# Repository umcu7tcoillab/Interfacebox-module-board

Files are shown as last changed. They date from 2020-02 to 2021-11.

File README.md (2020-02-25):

# Interfacebox module board

## About us
This design has been made by the coil-lab of the High Field MRI Group of the UMC Utrecht in the Netherlands, where we make hardware to support our researchers. We are part of a research group which means we feel the need to open up some of our designs to whomever can make use of it, to further the research of MRI applications.

## The design
This project contains a interfacebox module board made to be used with our driverboard, malfunctionboard and preamp board for our 7T Philips Achieva MRI system. It has been tested inside the magnetic field of the 7T MRI. 

The module board is designed to facilitate the making of an interfacebox, using our custom made PCB's. All the different modules can be attached to this board, making it act as an interfacebox.
There is an option to choose between 8 or 16 channels.

The design and subsequent drawing has been done in Kicad 5.1.5.

## Download
Gerber and BOM production files for the latest _field tested_ version of the PCB can be found in the 'Releases' page, or by following [this link](https://github.com/umcu7tcoillab/Interfacebox-module-board/releases/latest). 
You can also make your own production files by downloading the Kicad project and generating them, but these are not guaranteed to have been field tested.

## Images
**3D Image**
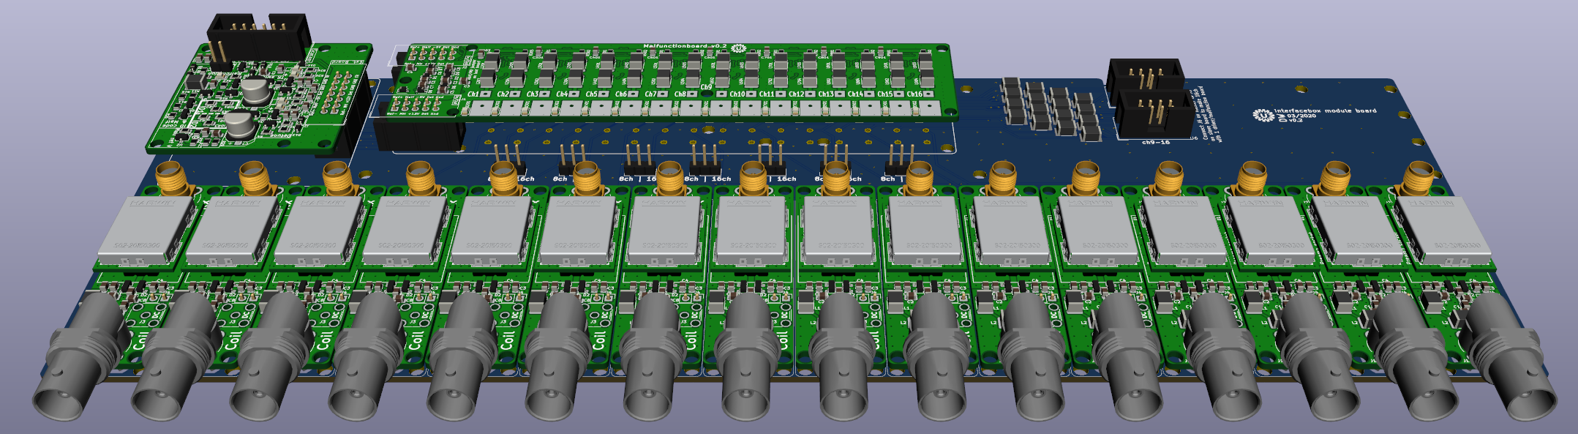
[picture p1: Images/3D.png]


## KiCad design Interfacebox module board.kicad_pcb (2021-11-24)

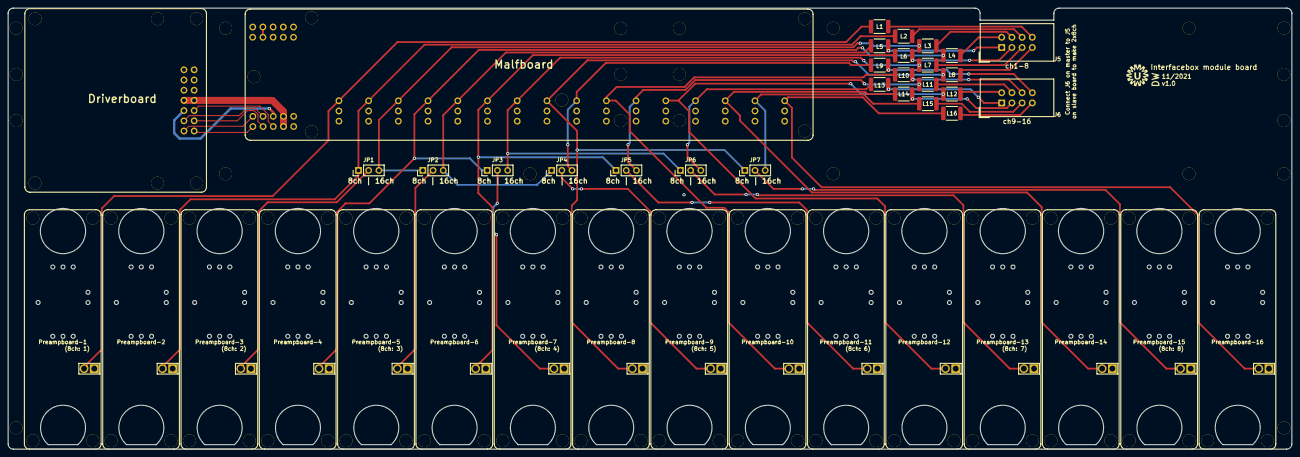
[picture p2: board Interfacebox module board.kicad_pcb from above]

Board: 2 copper layers, 319.7 x 109.8 mm, 58 parts (0 on the bottom side), 48 nets.

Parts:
G1: UMC_logo; UMC_logo_small
H1, H2, H4, H6, H10, H11, H12, H13, H14, H15: MH_Pad; MountingHole_3.2mm_M3_plated
J4: Driverboard
J5: 1-8; IDC-Header_2x04_P2.54mm_Vertical
J6: 9-16; IDC-Header_2x04_P2.54mm_Vertical
JP1, JP2, JP3, JP4, JP5, JP6, JP7: Jumper; PinHeader_1x03_P2.54mm_Vertical
L1, L2, L3, L4, L5, L6, L7, L8, L9, L10, L11, L12, L13, L14, L15, L16: choke; L_1812_4532Metric
MB1: Malfboard; Malfunctionboard
Preampboard-1, Preampboard-2, Preampboard-3, Preampboard-4, Preampboard-5, Preampboard-6, Preampboard-7, Preampboard-8, Preampboard-9, Preampboard-10, Preampboard-11, Preampboard-12, Preampboard-13, Preampboard-14, Preampboard-15, Preampboard-16: Preampboard
SYM3, SYM4, SYM5, SYM6: RXE4

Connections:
+12V: J4.5, MB1.B5
-5V: J4.6, MB1.B6
GND: H1.1, H2.1, H4.1, H6.1, H10.1, H11.1, H12.1, H13.1, H14.1, H15.1, J4.9, J4.10, J4.11, J4.12, MB1.1, MB1.B9, MB1.B10, MB1.T9, MB1.T10, Preampboard-1.1, Preampboard-2.1, Preampboard-3.1, Preampboard-4.1, Preampboard-5.1, Preampboard-6.1, Preampboard-7.1, Preampboard-8.1, Preampboard-9.1, Preampboard-10.1, Preampboard-11.1, Preampboard-12.1, Preampboard-13.1, Preampboard-14.1, Preampboard-15.1, Preampboard-16.1, SYM3.1, SYM4.1, SYM5.1, SYM6.1
Malf: J4.4, MB1.B4
Malf_MH: J4.3, MB1.B3
unnamed: J5.1, L5.1
unnamed: J5.2, L4.1
unnamed: J5.3, L6.1
unnamed: J5.4, L3.1
unnamed: J5.5, L7.1
unnamed: J5.6, L2.1
unnamed: J5.7, L8.1
unnamed: J5.8, L1.1
unnamed: J6.1, L13.1
unnamed: J6.2, L12.1
unnamed: J6.3, L14.1
unnamed: J6.4, L11.1
unnamed: J6.5, L15.1
unnamed: J6.6, L10.1
unnamed: J6.7, L16.1
unnamed: J6.8, L9.1
unnamed: JP1.1, L2.2, MB1.Rx2, Preampboard-2.2
unnamed: JP1.2, Preampboard-3.2
unnamed: JP1.3, JP2.1, L3.2, MB1.Rx3
unnamed: JP2.2, Preampboard-5.2
unnamed: JP2.3, JP4.1, L5.2, MB1.Rx5
unnamed: JP3.1, L4.2, MB1.Rx4, Preampboard-4.2
unnamed: JP3.2, Preampboard-7.2
unnamed: JP3.3, JP6.1, L7.2, MB1.Rx7
unnamed: JP4.2, Preampboard-9.2
unnamed: JP4.3, L9.2, MB1.Rx9
unnamed: JP5.1, L6.2, MB1.Rx6, Preampboard-6.2
unnamed: JP5.2, Preampboard-11.2
unnamed: JP5.3, L11.2, MB1.Rx11
unnamed: JP6.2, Preampboard-13.2
unnamed: JP6.3, L13.2, MB1.Rx13
unnamed: JP7.1, L8.2, MB1.Rx8, Preampboard-8.2
unnamed: JP7.2, Preampboard-15.2
unnamed: JP7.3, L15.2, MB1.Rx15
unnamed: L1.2, MB1.Rx1, Preampboard-1.2
unnamed: L10.2, MB1.Rx10, Preampboard-10.2
unnamed: L12.2, MB1.Rx12, Preampboard-12.2
unnamed: L14.2, MB1.Rx14, Preampboard-14.2
unnamed: L16.2, MB1.Rx16, Preampboard-16.2
unnamed: MB1.T3, MB1.T4
Ref_V+: J4.2, MB1.B2
Ref_V-: J4.1, MB1.B1
detune_in: J4.7, J4.8, MB1.B7, MB1.B8

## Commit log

2020-02-25 Added: connectors to distribute 16ch to 2 boards
    [Interfacebox module board.kicad_pcb, Interfacebox module board.sch]
2020-02-25 Added: slot for ribbon cable
    [Interfacebox module board.kicad_pcb]
2020-02-25 Changed: comments; README. Added: 3D render
    [Interfacebox module board.kicad_pcb]
2020-02-26 Changed: Removed unnecessary references in file
    [Interfacebox module board.sch]
2020-03-05 Added: holes for preamp socket pins, via's. Changed: 3D settings
    [Interfacebox module board.kicad_pcb]
2020-03-12 Added: outisde diameter
    [Interfacebox module board.kicad_pcb]
2020-03-13 Added: mounting holes for 2 RXE4's
    [Interfacebox module board.kicad_pcb, Interfacebox module board.sch]
2020-03-18 Changed: better and new footprint for malfunctionboard
    [Interfacebox module board.kicad_pcb, Interfacebox module board.sch]
2020-03-19 Updated: preamp footprint to accommodate preci-dip connectors. Added: some GND via's
    [Interfacebox module board.kicad_pcb]
2020-03-19 Added: missing logo
    [Interfacebox module board.kicad_pcb, Interfacebox module board.sch]
2021-11-24 Small changes. V0.3
    [Interfacebox module board.kicad_pcb, Interfacebox module board.sch]
2021-11-24 Updated to v1.0
    [Interfacebox module board.kicad_pcb, Interfacebox module board.sch]
